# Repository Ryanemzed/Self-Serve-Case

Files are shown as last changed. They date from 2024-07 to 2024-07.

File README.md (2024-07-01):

# Ryanemzed's Self Serve Case Guide

## Buttons Matter

I started my journey building rectangles by trying to make a controller for my brother that didn't suck, and a big part of that was realizing that what the folks in the US were doing with keyboard switches was just not at all accessible to me in Canada before services like SendCutSend opened up affordable shipping recently.

I've spent the past two years tinkering with buttons of various types trying to figure out ways to make the most of what I had access to, and in all of my work I feel like arcade buttons still have a place in the current scene. Of course, a big factor behind that is that the OBSF-24 buttons from Sanwa remain a popular option in the FGC at large, but more specifically because they don't require the specific design consideration of having a switchplate for the keyboard switches.

Enter the files in this GitHub.

## A Flexible Set of Files

The design language is heavily lifted from the builds I do by commission, the Chocwa Bar & Chocwa Bar Mini, using curved channels to guide the wiring from the button clusters to the microcontroller and maintaining as much material infill as possible to preserve rigidity when using materials such as acrylic.  

You're going to need to do some investigating to figure out how to make these files work for you, but you can come to Crane's discord to ask me questions about how to plan a build that will work for your needs. Things like tolerances, your comfort level with soldering, and even the materials you're hoping to use can throw some curve balls that take some work to figure out.  

For now, know that my primary objective is to provide a platform for people to build something that is sleek while reducing the case footprint as much as possible using more widely accessible processes and materials.

## How To Use These Files

The way to make sense of this is to think of it as a top to bottom set of slices. You will always need a Button Panel that's 3mm thick, then you'll want 6mm worth of Under Panel (either one 6mm layer or two 3mm), and then your port/cable layer also 3mm. Where the most variability will come from is in the Wiring layers underneath, as that's where all of your wiring spaghetti lives. And then of course, you'll need a bottom panel.

As an example, let's imagine you're building with stock Sanwas, want a USBC combo port, and are planning to use quick disconnect terminals. Let's look at the layers we'll need:

- [ ] 1 x 3mm Button Panel  
- [ ] 2 x 3mm Under Panel (or 1 x 6mm)  
- [ ] 1 x 3mm USBC Panel  
- [ ] 7 x 3mm Wiring Panel (or 3 x 6mm + 1 x 3mm)  
- [ ] 1 x 3mm Bottom Panel  

This provides us the amount of space we need to just fit in stock Sanwas and their connectors with a bit of elbow grease, with a total case depth top to bottom of 36mm. This leaves an internal working space with the wiring layers of 21mm, which should be plenty of room for activities with a wire range of microcontrollers and with soldering or even screw terminals.  

In general, you're going to adjust your layer selection based on the buttons you're intending to use, accounting for the types of connectors they use and how much room you need to get them connected up. Modding the buttons in different ways can allow for a lot of savings in overall depth and fewer layers required, such as in the mods I perform as seen in my other GitHub repositories.  

Lastly, there are multiple remixes of each layer, which are meant to address variables such as the types of bolts & nuts or the usbc breakout board intended to be used. To start, all of the designs presuppose you will be using sets of M6 bolts [such as these](https://www.amazon.com/uxcell-Binding-Leather-Fastener-M6x20mm/dp/B07QB68F9K/), which can be found on amazon all around the world as well as places like [AliExpress](https://www.aliexpress.com/item/1005001560902304.html) in a variety of lengths to match the final case design you settle on.

If choosing to use a USB-C Breakout Board, see [this guide for wiring suggestions.](UsbcBreakoutWiringGuide.md)

## The Files

For now, please find all of the files I've developed under [case-files](case-files)

They are split into 5 panel types:

**Panel 1 - Button Plates** (3mm)  
This is the layer of acrylic your 24mm buttons will snap into. It's important that this layer is 3mm to hold the buttons properly.  

**Panel 2 - Underplates** (6mm)  
This is what goes directly underneath your button plate, helping to keep your buttons and their panel supported and making your build as sturdy as possible.  

**Panel 3 - USBC** (3mm)  
This layer is what sandwiches your USBC breakout board into place. It relies on you doing some hand wiring to use cheap and commmonly available breakout boards from [AliExpress](https://www.aliexpress.com/item/1005001300974530.html), or ordering specially designed breakouts that simplify the wiring greatly [as found in Hadoe's GitHub](https://github.com/HTangl/HTUB)  
There are versions of this layer adapted for each type of breakout board and are labelled accordingly, or you can opt to do a permanently connected cable instead.  

**Panel 4 - Wiring Routing** (???mm)  
As I said above, this layer is where it's most important for you to know what you need. Here is where you make more room for buttons and connectors that are taller, or can save on bulk if you're using something shorter like a Bao Button found in my [GitHub](https://github.com/Ryanemzed/Bao-Button-Mods) on the mod.  

**Panel 5 - Bottom Cover** (3mm)  
Thankfully, there's nothing special here to worry about: its only job is to close things up :)  

Some handy tips to keep in mind:  

- 3mm clear acrylic is always cheapest
- Ordering more than one of a layer makes the layers cheaper
- 6mm clear acrylic is a nice option to make things easier to handle while building
- MDF is a viable material option if it's cheap enough
- Some places will offer wood, which can have a nice look to it when stained  

As a tip, I like to do a clear acrylic button panel and then a cool type of material underneath like stained wood which protects it from wear and tear. Another idea is a clear acrylic top layer, and then printing out a piece of art you like to go under that panel and spare you from having to see all of your wiring spaghetti under it ;)

## Example Builds

So far, I've had two people use the files here to make their own controllers, and I'm super thankful to both of them for trusting my work to make themselves something they can use to enjoy the beautiful game of Melee.

V_Rin's build:


Her build used Baolians I MX modded for her, and she was able to get a case depth of 30mm

Zedy's build:


His build reused components from his DIY build he had done using a Hammond steel case and stock sanwas, and with a little cruelty he was able to make things work. The issue here was that we needed to add one more layer of material to the wiring channels to account for tolerances in the acrylic, so he didn't have quite enough room for his button terminals and had to solder his ground loop on rather than using the existing QDC terminals. That said, he was able to accomplish a build totaling 33mm case depth, reducing the physical bulk and heft he was unhappy with coming from the Hammond case significantly.

## Questions

If you'd like to ask any questions, please feel free to @ me in [Crane's discord](https://discord.gg/S3qgZWD), where I am active and spend a lot of time discussing builds and work to help others accomplish their own builds in between joking around :)

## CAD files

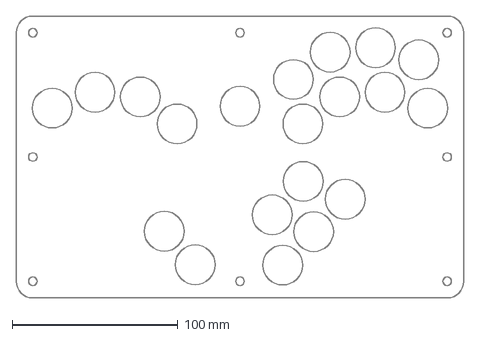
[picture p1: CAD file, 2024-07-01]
case-files/Self Serve - Mini/1 - Button Panel/1 - McM.dxf
270.0 x 170.0 mm

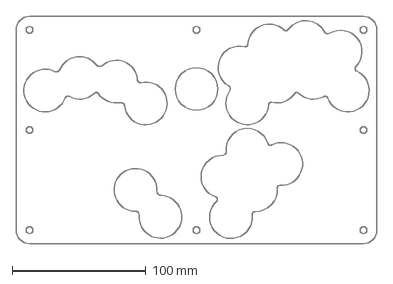
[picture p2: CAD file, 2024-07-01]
case-files/Self Serve - Mini/2 - Under Panel/2 - McM.dxf
270.0 x 170.0 mm

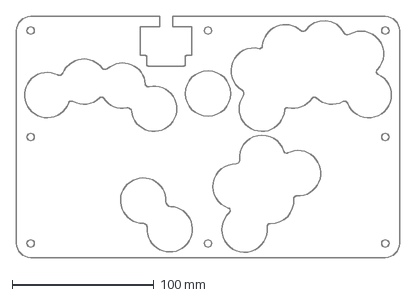
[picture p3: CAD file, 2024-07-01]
case-files/Self Serve - Mini/3 - USBC/3 - McM - AE.dxf
270.0 x 170.0 mm

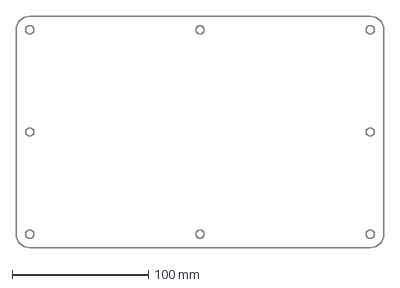
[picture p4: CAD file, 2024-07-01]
case-files/Self Serve - Mini/5 - Bottom Panel/5 - UXC.dxf
270.0 x 170.0 mm

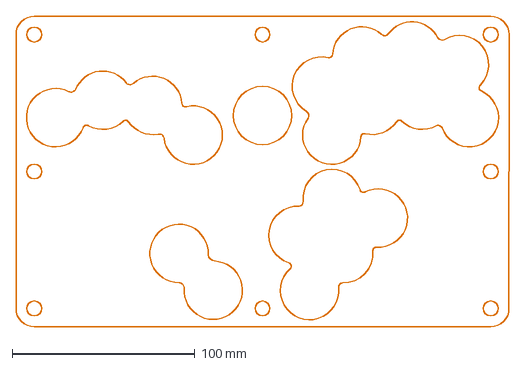
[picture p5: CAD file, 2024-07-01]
case-files/Self Serve - Mini/Full Stack Files/Self Serve Mini Build MASTER.dxf
270.0 x 170.0 mm

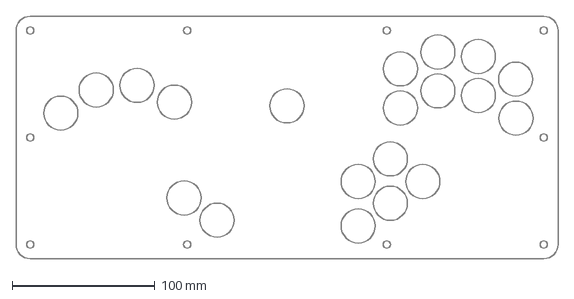
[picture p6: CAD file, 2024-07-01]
case-files/Self Serve - Standard/1 - Button Panel/1 - McM.dxf
380.0 x 170.0 mm

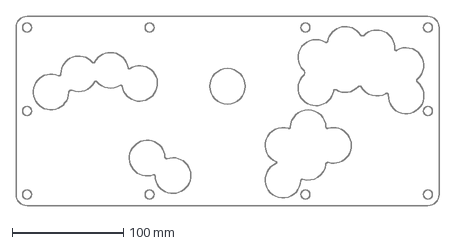
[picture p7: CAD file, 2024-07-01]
case-files/Self Serve - Standard/2 - Under Panel/2 - UXC.dxf
380.0 x 170.0 mm

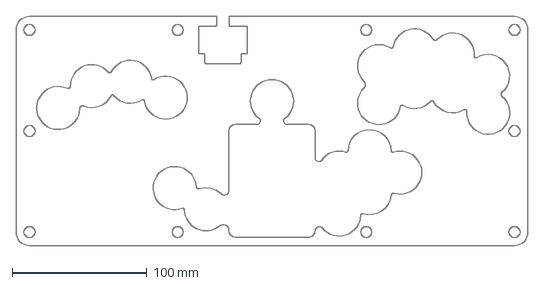
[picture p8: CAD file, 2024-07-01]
case-files/Self Serve - Standard/3 - USBC/3 - UXC - AE.dxf
380.0 x 170.0 mm

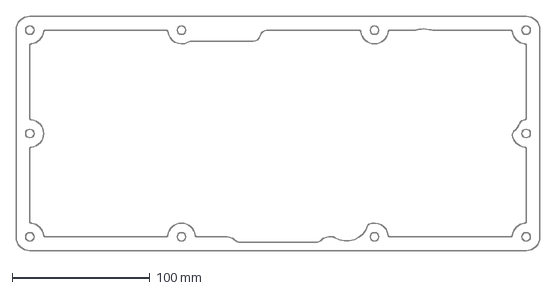
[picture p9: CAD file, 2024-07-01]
case-files/Self Serve - Standard/4 - Wiring Panel/4 - UXC - AE - Hollow.dxf
380.0 x 170.0 mm

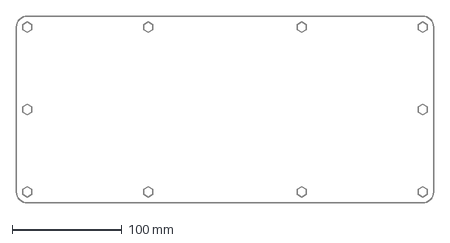
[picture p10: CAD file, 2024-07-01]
case-files/Self Serve - Standard/5 - Bottom Panel/5 - McM.dxf
380.0 x 170.0 mm

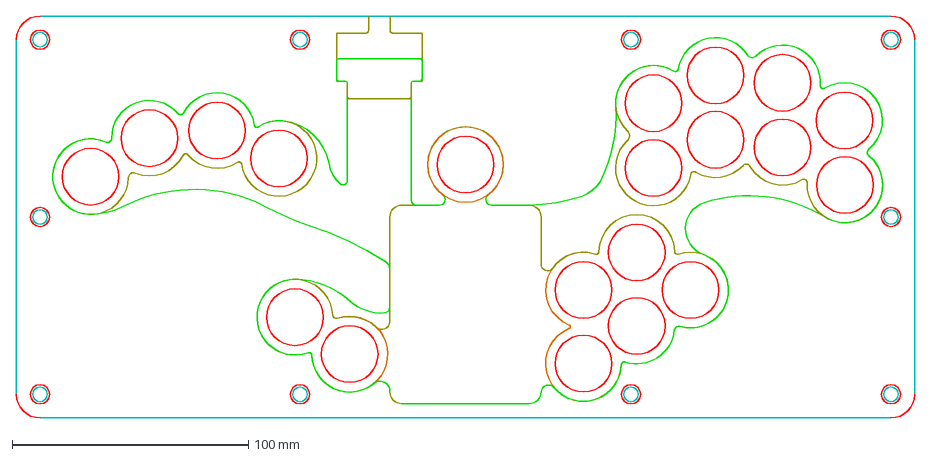
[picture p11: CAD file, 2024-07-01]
case-files/Self Serve - Standard/Revamped Self Serve Case - WIP.dxf
380.0 x 170.0 mm

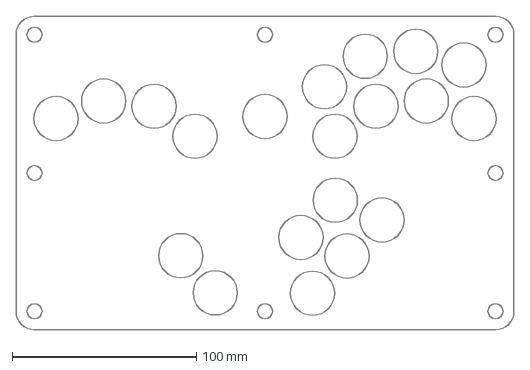
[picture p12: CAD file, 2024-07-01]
case-files/Self Serve - Mini/1 - Button Panel/1 - UXC.dxf
270.0 x 170.0 mm

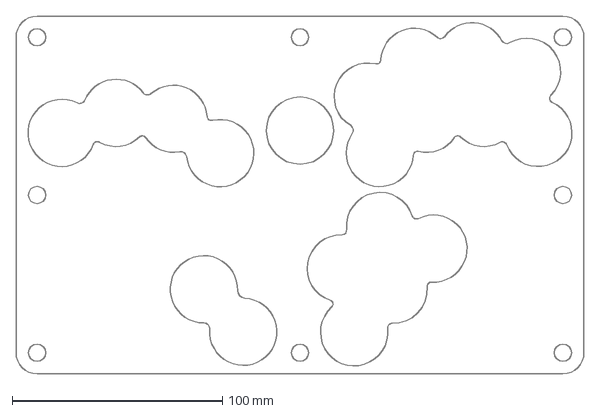
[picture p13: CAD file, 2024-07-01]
case-files/Self Serve - Mini/2 - Under Panel/2 - UXC.dxf
270.0 x 170.0 mm

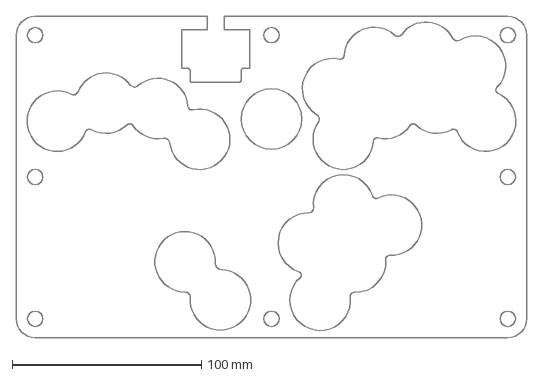
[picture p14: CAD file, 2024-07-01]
case-files/Self Serve - Mini/3 - USBC/3 - UXC - AE.dxf
270.0 x 170.0 mm

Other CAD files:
case-files/Self Serve - Mini/4 - Wiring Panel/4 - UXC - AE - Hollow.dxf
case-files/Self Serve - Mini/5 - Bottom Panel/5 - McM.dxf
case-files/Self Serve - Standard/1 - Button Panel/1 - UXC.dxf
case-files/Self Serve - Standard/2 - Under Panel/2 - McM.dxf
case-files/Self Serve - Mini/3 - USBC/3 - McM - HT.dxf
case-files/Self Serve - Mini/3 - USBC/3 - UXC - HT.dxf
case-files/Self Serve - Mini/4 - Wiring Panel/4 - McM - AE - Hollow Nut Spacer.dxf
case-files/Self Serve - Mini/4 - Wiring Panel/4 - McM - AE - Hollow.dxf
case-files/Self Serve - Mini/4 - Wiring Panel/4 - McM - AE - Nut Spacer.dxf
case-files/Self Serve - Mini/4 - Wiring Panel/4 - McM - AE.dxf
case-files/Self Serve - Mini/4 - Wiring Panel/4 - McM - HT - Hollow Nut Spacer.dxf
case-files/Self Serve - Mini/4 - Wiring Panel/4 - McM - HT - Hollow.dxf
case-files/Self Serve - Mini/4 - Wiring Panel/4 - McM - HT - Nut Spacer.dxf
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

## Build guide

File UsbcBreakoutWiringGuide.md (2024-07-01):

# Ali Express USBC combo port wiring guide

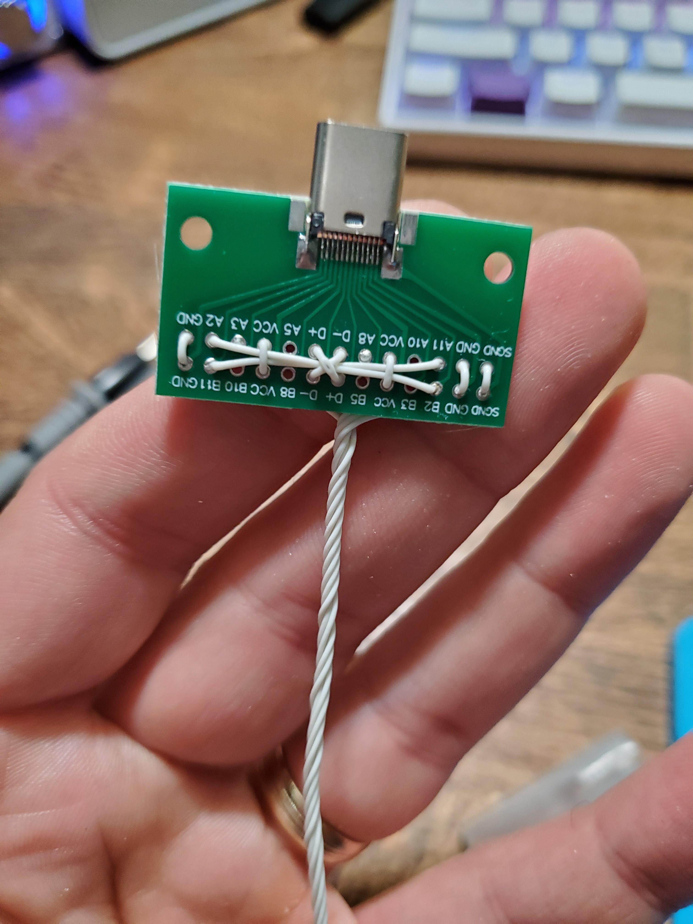
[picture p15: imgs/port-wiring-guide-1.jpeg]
Pictured: What a finished port should look like on it's "top" side if you follow this guide

*Pictured: What a finished port should look like on it's "top" side if you follow this guide*

If you're wondering why anyone would use these ports, it's because they can fit in layered 3mm acrylic design snugly and are cheaply available on Ali Express world wide. Sellers change frequently, so I can't post a link to one in particular and be confident it'll still be active in the future.

When preparing your port, you will want to choose which side is going to be the pretty one and which will be the back side. On a clear build, having the top facing the button panel is absolutely preferable, but on some builds you might have art or some other design that means the viewing angle of the port is from the underside of the build.

**IMPORTANT NOTE:** DO NOT cut your wires off at the port; you will want to thread them through as per the wiring guide that follows, and then cut them to length required to your microcontroller/solder points. It's not the end of the world if you cut them off, but keeping each of the steps continuous means you only need one wire for the entire bridging and connection process.

**ALSO:** This port cannot support USBC-USBC cables; if that matters to you, you should order a port from folks in the community such as the Model U, Model UD, Model Bird, Model BirdD, HTUB, etc. These can all be found in the Crane's Lab discord via the #vendors channel.

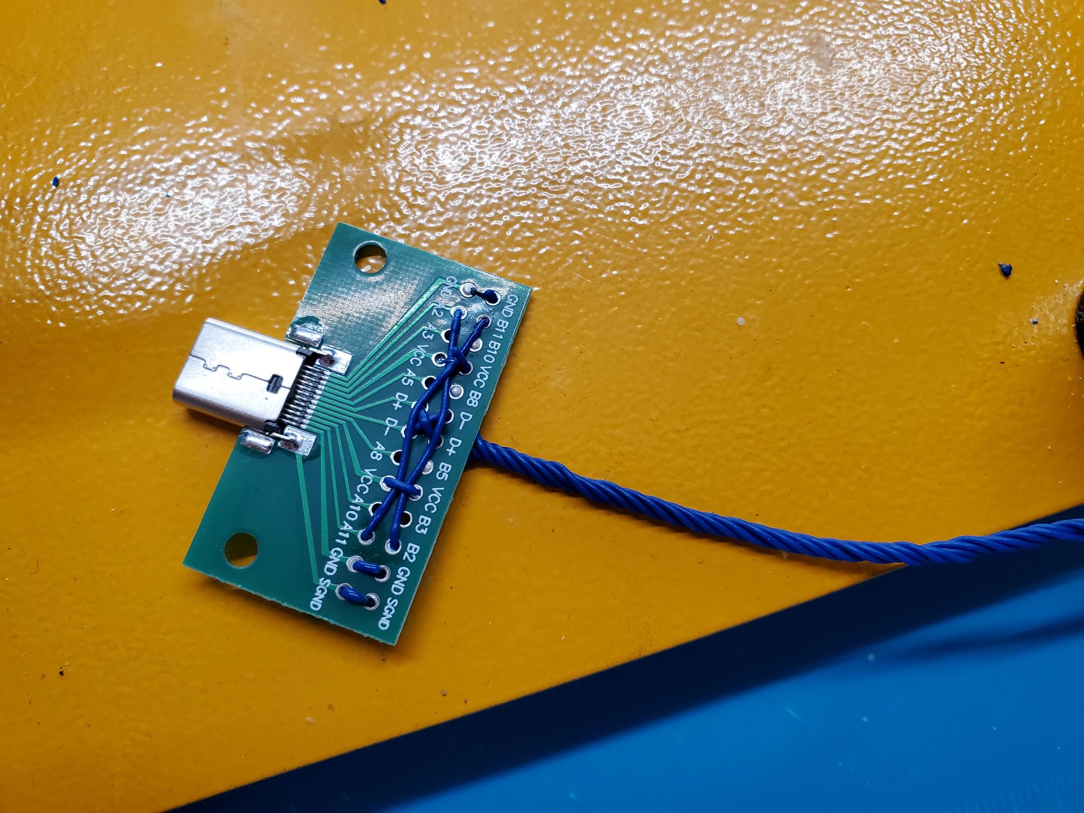
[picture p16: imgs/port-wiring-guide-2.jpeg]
Pictured: Another port prepared in the same way.

*Pictured: Another port prepared in the same way.*

Each step will be shown bottom view then top view before moving to the next step. the direction you do it in doesn't matter TOO much, there's room for flexibility especially on the bottom side for the order/arrangement. I'd recommend making sure your top side matches closely though, and don't have more than 3 wires stacked to prevent them getting too thick to fit into your 3mm acrylic layers.

Let's begin.

## Step 1

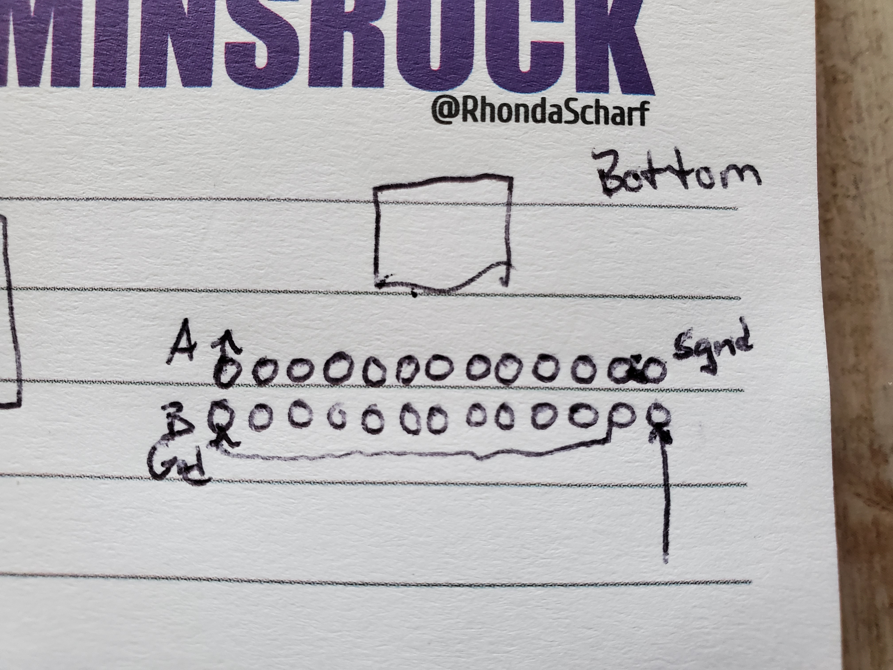
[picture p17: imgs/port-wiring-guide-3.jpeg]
Bottom: Ground.

*Bottom: Ground*

Note the arrows showing the direction the wires go in/out from each pins. Route the connection between sides in such a way that it doesn't interfere with access to other pins and your room to solder.

Leave slack as you weave it through, then start from the end point and pull one or two joints tight from that spot to prepare for soldering it in. Depending on the sheathing of your wire and the quality of your solder, you might be able to simply melt the plastic away to make your joint. To avoid the risk of melting the sheathing off completely, I use a craft knife to cut notches into the sheathing at the location of the joint to make getting a connection more consistent.

**IMPORTANT NOTE:** Do all your soldering from the bottom side! It keeps the top clean.

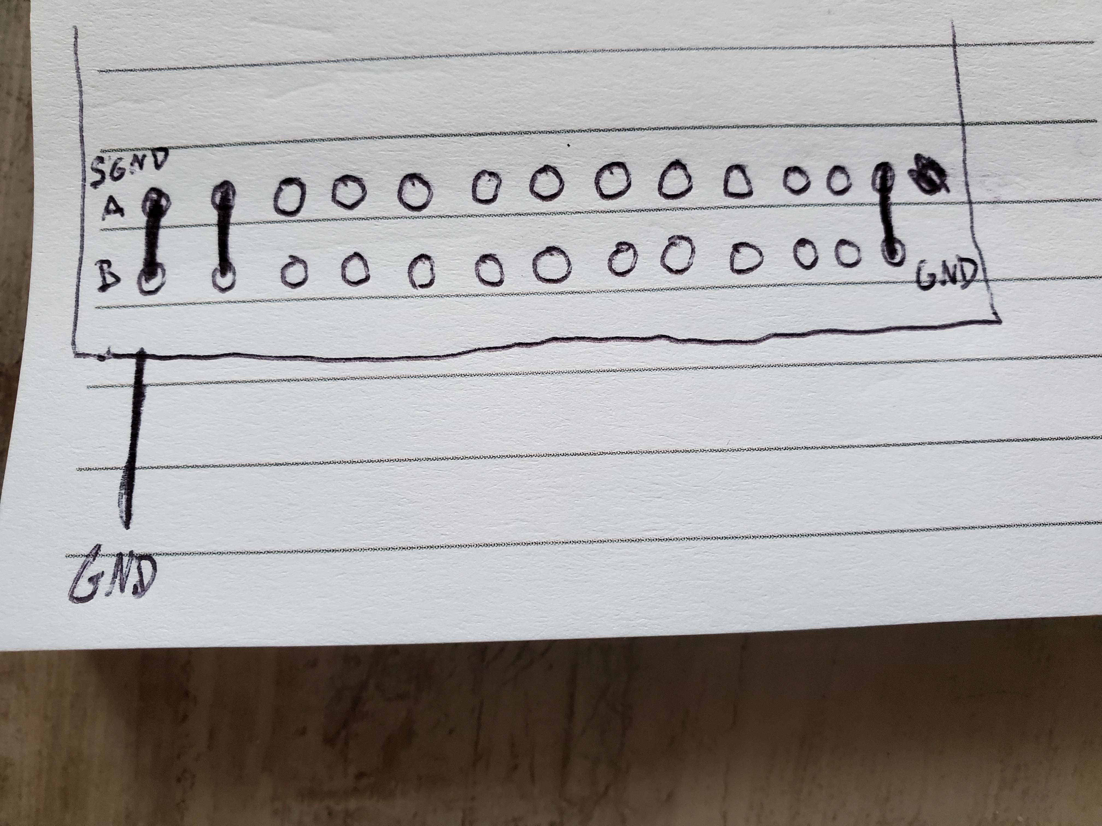
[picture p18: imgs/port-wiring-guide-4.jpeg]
Top: What your runs should look like on top

*Top: What your runs should look like on top*

## Step 2

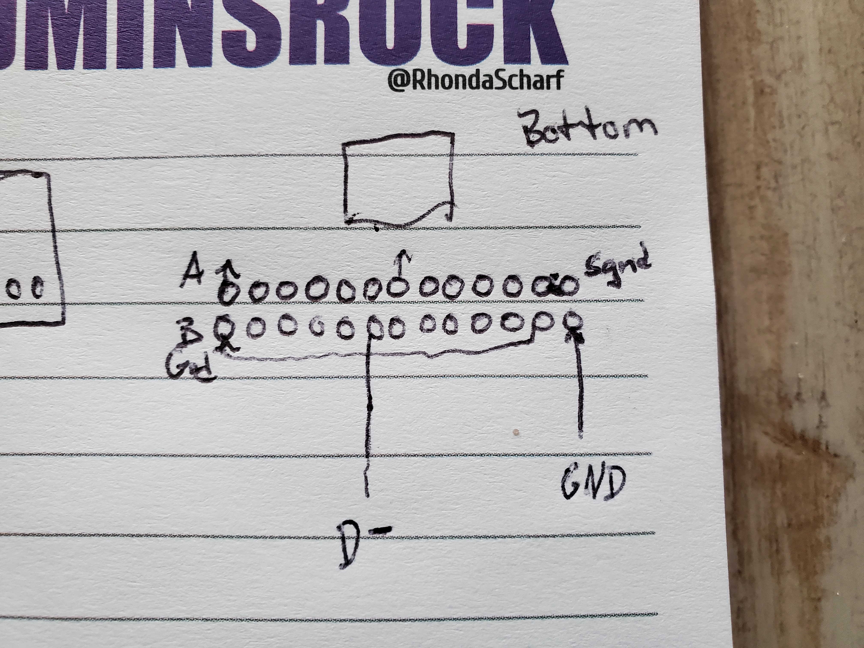
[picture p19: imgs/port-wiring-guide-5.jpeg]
Bottom: USB data lines. D- or D+ first makes no difference, but do them both at this point.

*Bottom: USB data lines. D- or D+ first makes no difference, but do them both at this point.*

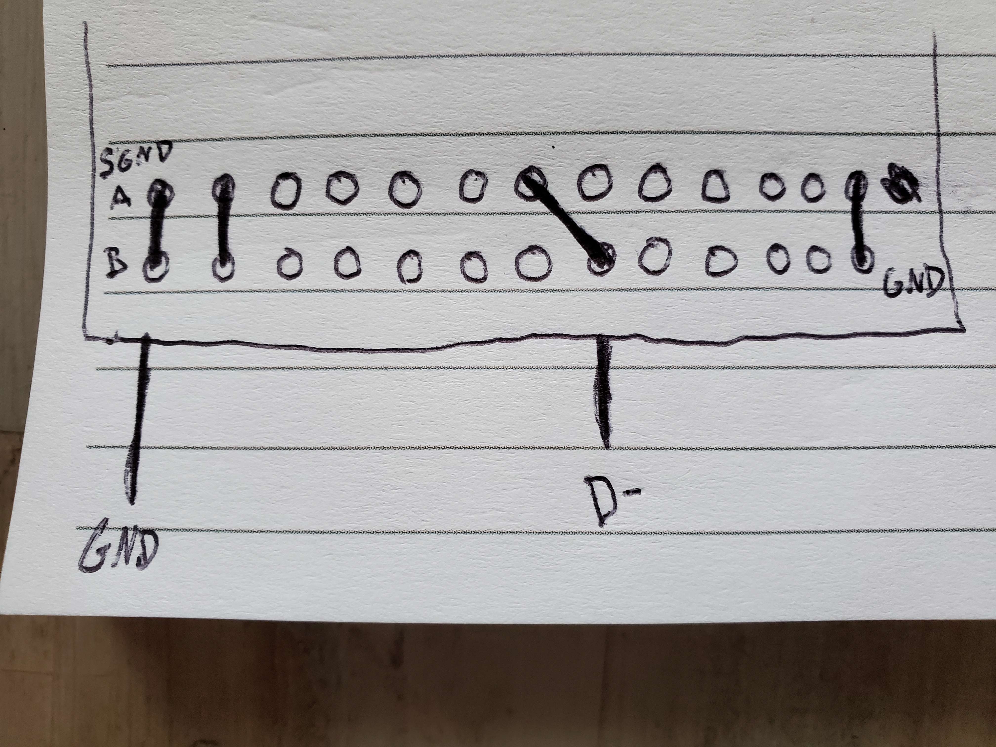
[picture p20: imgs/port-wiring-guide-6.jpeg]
Top: Data -

*Top: Data -*

## Step 3

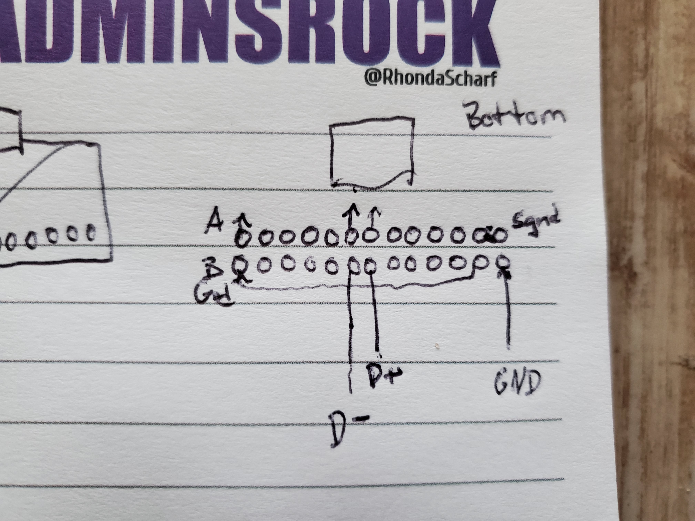
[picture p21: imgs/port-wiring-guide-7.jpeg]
Bottom: Data +

*Bottom: Data +*

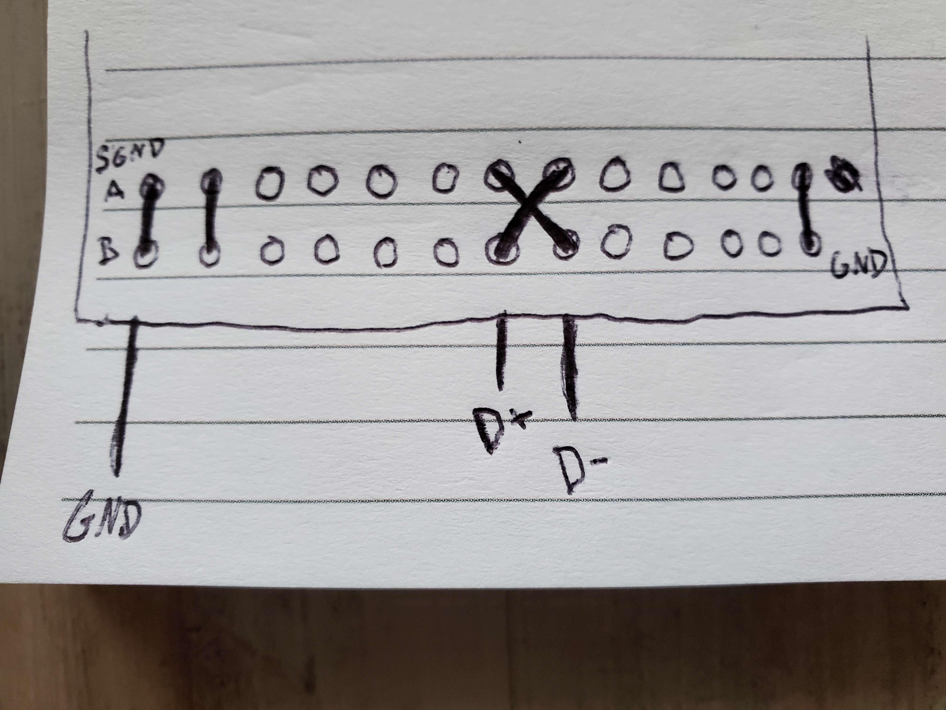
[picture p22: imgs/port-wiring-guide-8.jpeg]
Top: Data +

*Top: Data +*

## Step 4

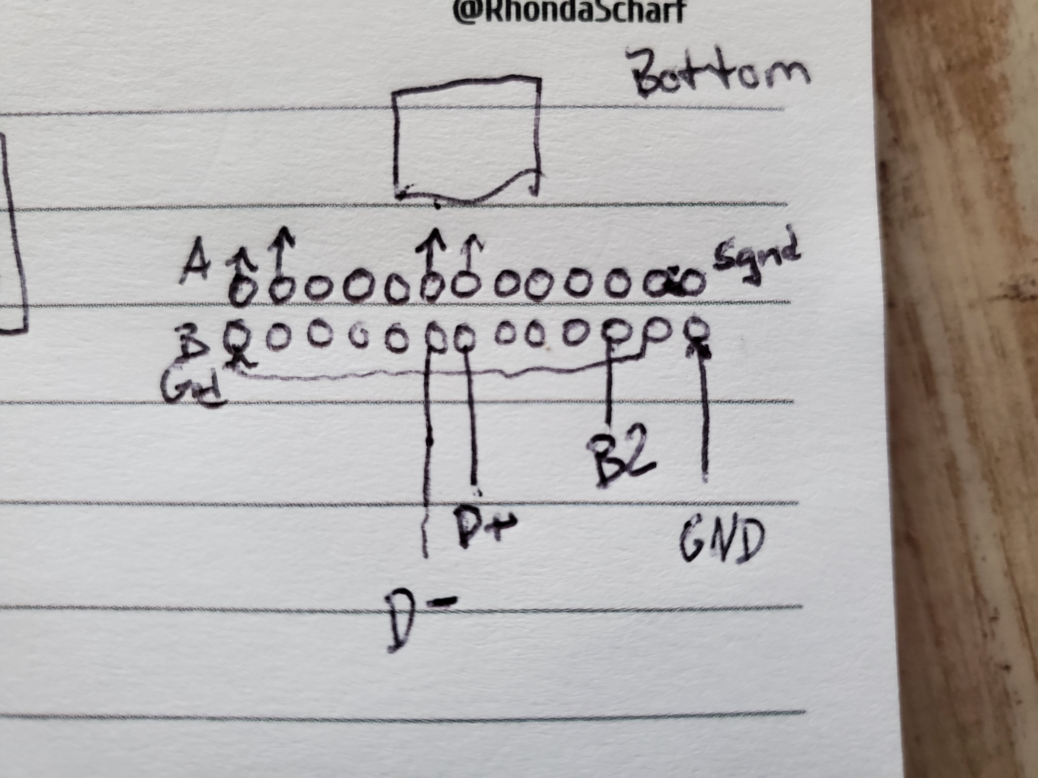
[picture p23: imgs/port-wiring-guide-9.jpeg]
Bottom: VSYS / 3.3V

*Bottom: VSYS / 3.3V*

**NOTE:** This is the wire your diode is part of. I mention this because I always forget and have to dig up the reference diagrams :P

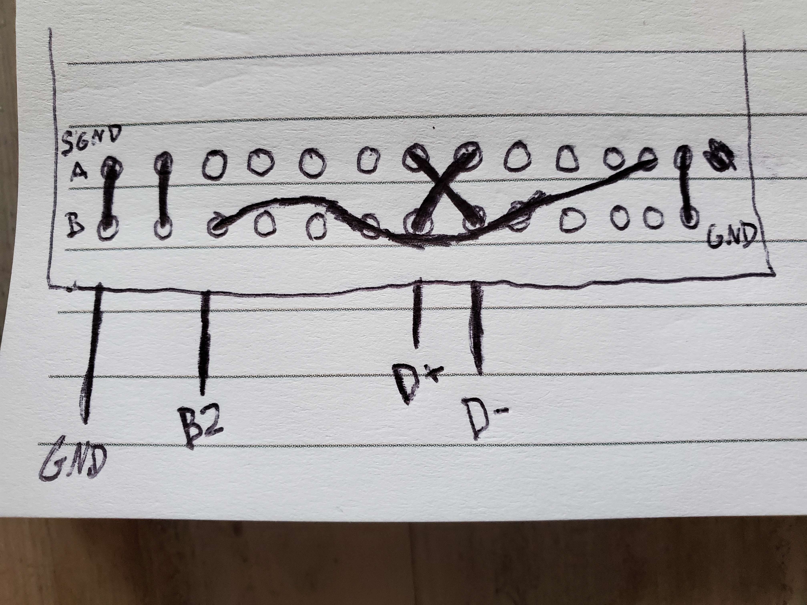
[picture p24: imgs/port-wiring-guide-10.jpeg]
Top: VSYS / 3.3V

*Top: VSYS / 3.3V*

## Step 5

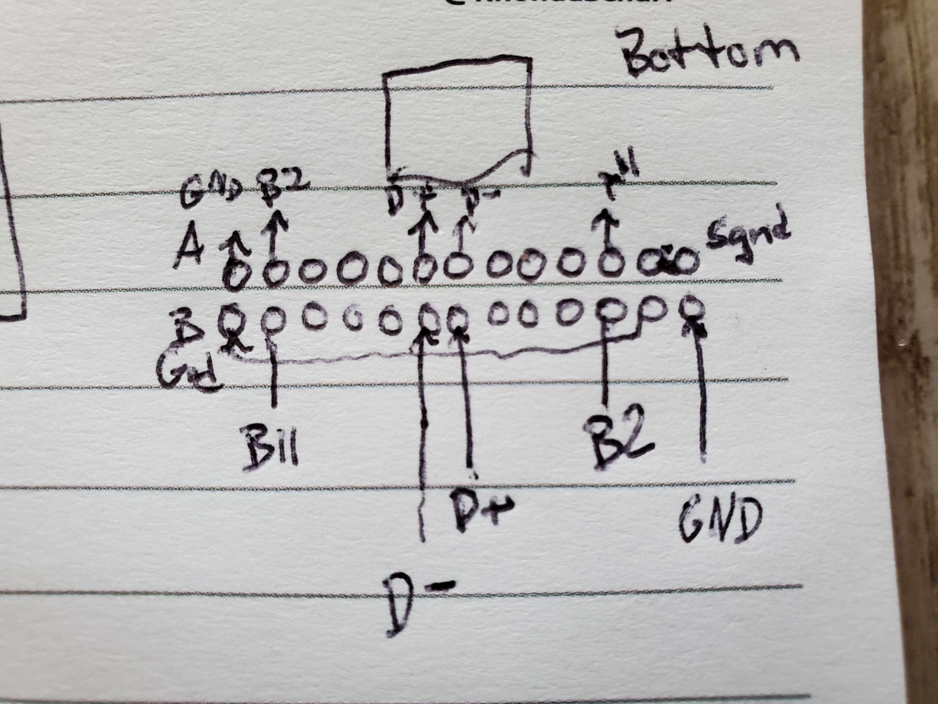
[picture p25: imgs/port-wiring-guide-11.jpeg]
Bottom: 3VD (GCC data line)

*Bottom: 3VD (GCC data line)*

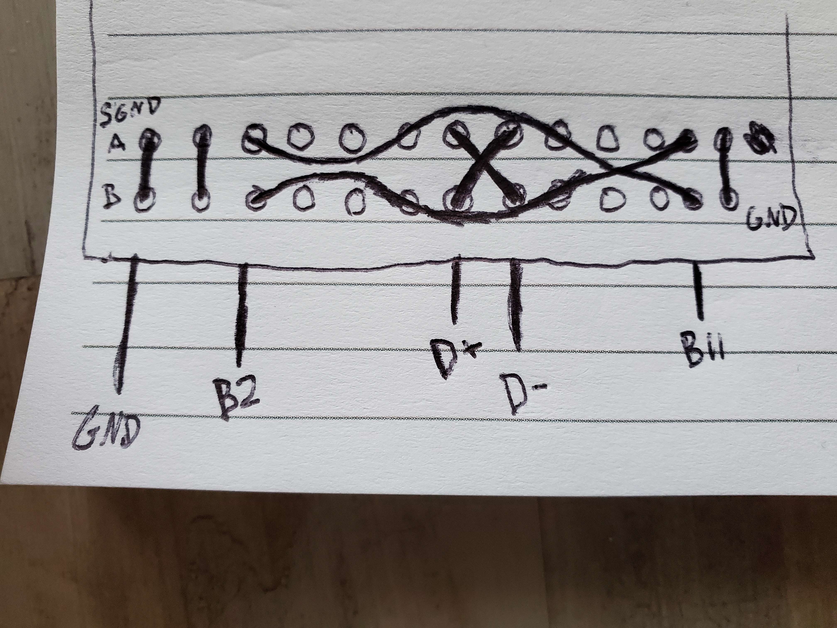
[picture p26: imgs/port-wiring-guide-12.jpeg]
Top: 3V D (GCC data line)

*Top: 3V D (GCC data line)*

**Note:** pay attention to the wire routing here specifically; the next and final step will make this make sense. If you're not sure what the relationship is here, refer back to the first two example images at the top of this post and look closely.

## Step 6

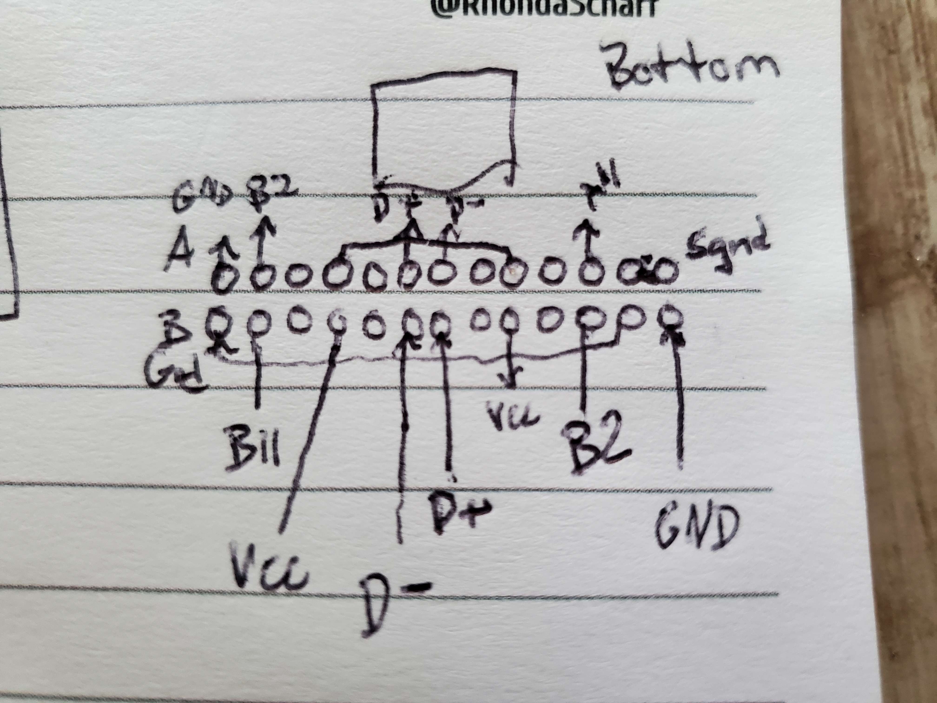
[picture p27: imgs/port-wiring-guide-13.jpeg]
Bottom: VCC / 5V

*Bottom: VCC / 5V*

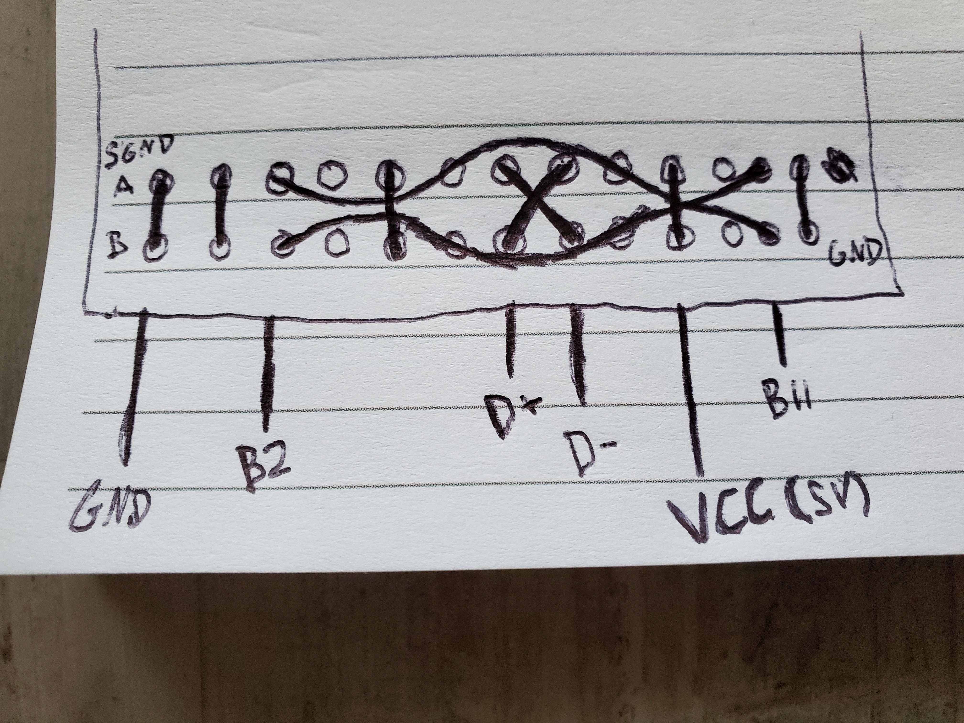
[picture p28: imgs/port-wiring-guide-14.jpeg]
Top: VCC / 5V

*Top: VCC / 5V*

**Note:** Use your 5v wires to pin the wires from steps 4 and 5 into place. Again, if you're unsure of what this means from image alone, please refer to the example images at the top of this post.

## Questions?

If you have any Qs, ask me in Crane's Lab!

- RMZC

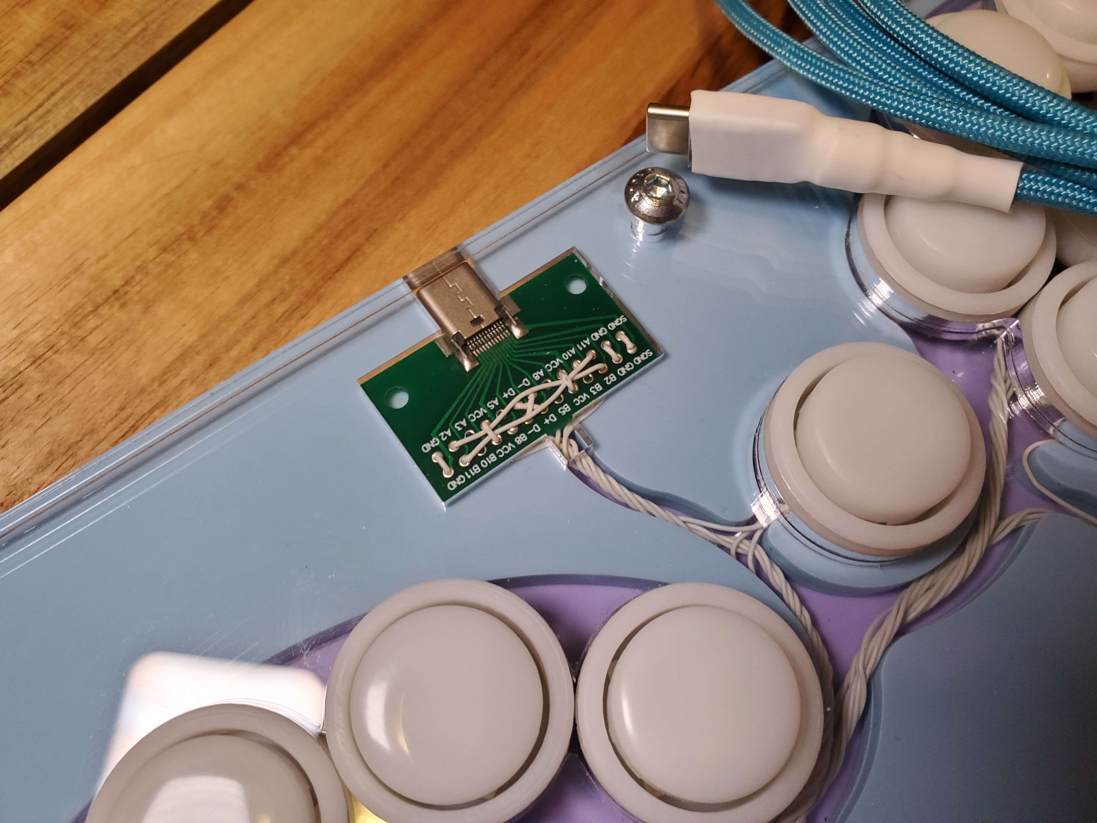
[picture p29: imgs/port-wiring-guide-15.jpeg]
P.S.: Here's the result in a build :)

*P.S.: Here's the result in a build :)*

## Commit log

2024-06-10 Adds all case files
    Adds case files originally in Google Drive to repository under
    `./case-files`, for easier access. Updates README
    [1 - McM.dxf, 1 - UXC.dxf, 2 - McM.dxf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]
2024-06-10 Init USBC Wiring Guide
    Updates README and inits usb wiring guide, originally from IMGUR
